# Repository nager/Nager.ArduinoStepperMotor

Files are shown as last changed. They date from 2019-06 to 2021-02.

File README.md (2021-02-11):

# Nager.ArduinoStepperMotor

This project was developed to control a stepper motor smoothly and to adjust the speed during operation. Most of the libaries I tested at that time had an acceleration curve but always stopped when changing to another speed and then started again. There are two ways to communicate with the Arduino, one is via serial communication or by using a network module. If you have difficulties and the motor only whistles you should adjust the acceleration curve in the Arduino file.

## Project Skier Simulator

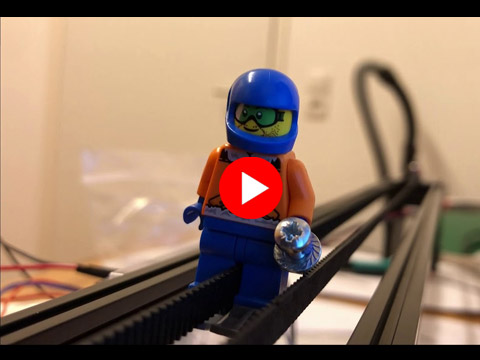
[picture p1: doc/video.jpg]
Youtube Video (https://www.youtube.com/watch?v=VNwVPjmE1V4)
<br>
Watch the video on Youtube

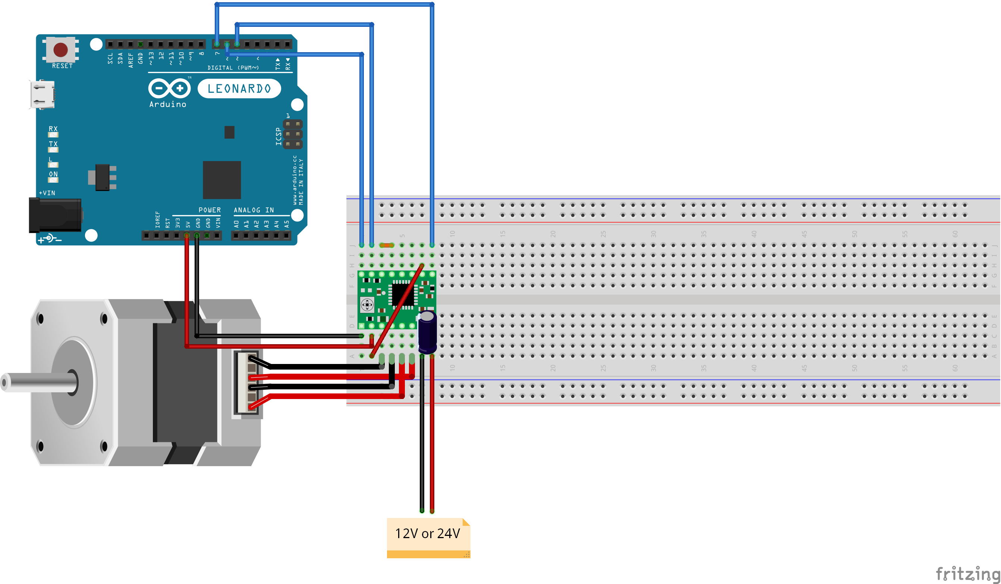
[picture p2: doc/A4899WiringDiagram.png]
A4899WiringDiagram

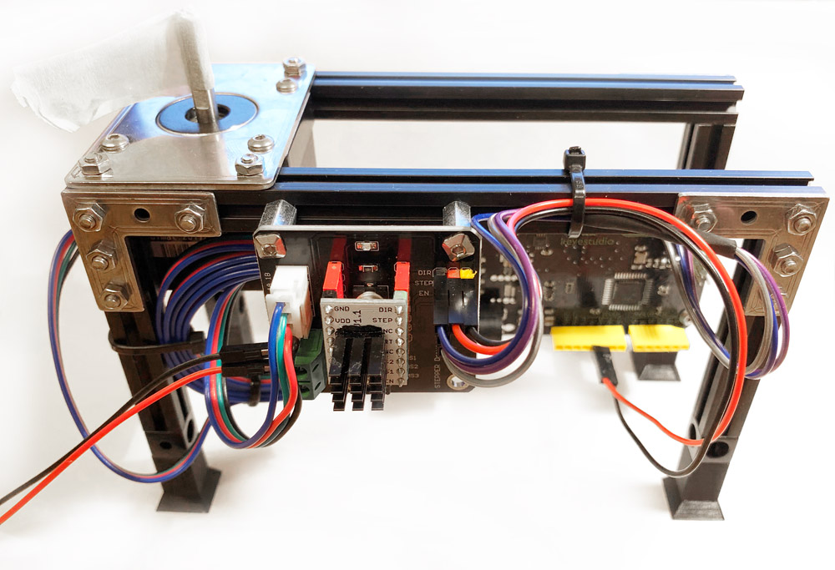
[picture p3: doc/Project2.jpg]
Project2


### Serial Commands (Baudrate 115200)

Command | Description | 
--- | --- | 
`enablemotordriver` | Enable the motor driver, the motor has voltage
`disablemotordriver` | Disable the motor driver, the motor has no voltage
`speed` | Values between -255 and 255
`limitenable` | The motor can only move between the limits
`limitdisable` | No limits active
`setlimitleft` | Set the current position as left limit
`setlimitright` | Set the current position as right limit
`step` | Motor move one step
`ramp` | Returns the current ramp
`setramp` | Set a new ramp (setramp=0008000) rampIndex 0 -> 8000

### Required Hardware

Quantity | Product | 
--- | --- | 
1x | [A4988 Stepper Driver Control Expansion Board](https://amzn.to/2X9j6cO) |
1x | [UEETEK 4 Stück 1M Stepper Motor Cable HX2.54 4-pin to 6-pin](https://amzn.to/31w3uz7) |
1x | [Usongshine Stepper Motor Nema 17 1.5A 17HS4401S](https://amzn.to/2KO4jO8) |
1x | [PChero Mechanic Endstop with LED Indicator](https://amzn.to/2UIAZh4) |

## Test Software

For control via serial communication I have developed a small test application.

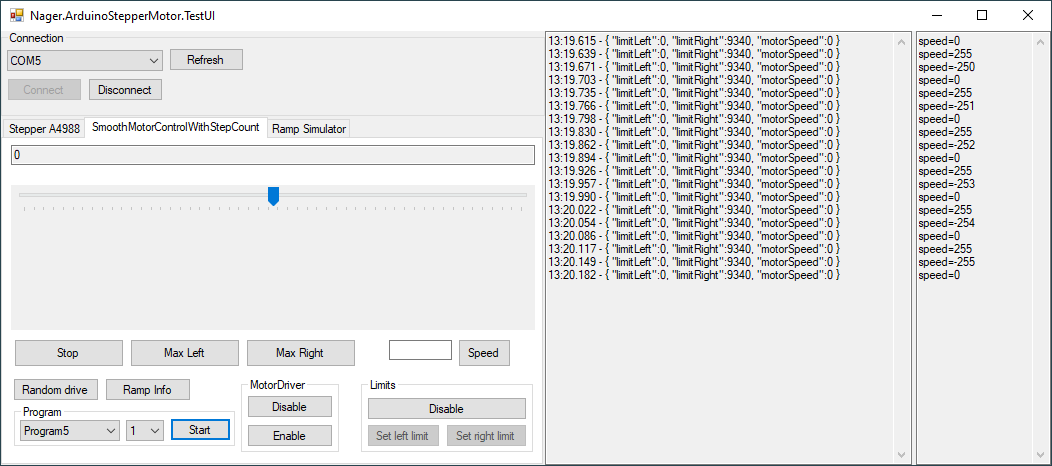
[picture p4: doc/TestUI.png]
TestUI


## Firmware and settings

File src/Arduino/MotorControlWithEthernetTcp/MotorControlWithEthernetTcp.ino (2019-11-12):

#include <SPI.h>
#include <Ethernet.h>

// Enter a MAC address and IP address for your controller below.
// The IP address will be dependent on your local network:
byte mac[] = { 0x06, 0x47, 0x3B, 0xA8, 0xF0, 0x9B };
IPAddress ip(192, 168 ,184, 65); //<<< ENTER YOUR IP ADDRESS HERE!!!

enum movementDirections {
  MOVEMENT_LEFT,
  MOVEMENT_RIGHT
};

int motorDriverActivePin = 7;
int stepPin = 5;
int directionPin = 6;

//Endstop configuration
bool endstopEnable = true;
int endstopRightPin = 2;
int endstopLeftPin = 3;

unsigned int counter = 0;
int onTime = 0;

String command = "";
bool limitActive = true;
unsigned long limitRight = 0;
unsigned long limitLeft = 0;
int motorDirection = 0; //0 or 1 rotates the motor direction

#define RAMP_STEPS 256
#define TIMERTICKS_PER_US 1

volatile unsigned int ramp[RAMP_STEPS];
volatile byte rampIndex = 0;
volatile int motorSpeed  = 0;
volatile unsigned long steps = 0;
volatile enum movementDirections movementDirection = MOVEMENT_RIGHT;
volatile enum movementDirections nextMovementDirection = MOVEMENT_RIGHT;

EthernetServer TcpServer = EthernetServer(23);
EthernetClient client;

void setup() {
  Serial.setTimeout(50);
  Serial.begin(115200);

  Ethernet.begin(mac, ip);
  TcpServer.begin();

  pinMode(motorDriverActivePin, OUTPUT); // Motor Driver Active
  pinMode(stepPin, OUTPUT); // Motor Step
  pinMode(directionPin, OUTPUT); // Motor Direction
  pinMode(endstopRightPin, INPUT); // Endstop

  digitalWrite(directionPin, motorDirection);
  digitalWrite(motorDriverActivePin, LOW);

  //https://www.heise.de/developer/artikel/Timer-Counter-und-Interrupts-3273309.html
  noInterrupts();           // disable all interrupts
  TCCR1A = 0;               // set entire TCCR1A register to 0
  TCCR1B = 0;               // set entire TCCR1B register to 0

  TCNT1 = 65534;

  //TCCR1B |= (1 << CS10);    // 4.1ms (No Prescale)
  TCCR1B |= (1 << CS11);    // 32.8ms (Prescale = 8)
  //TCCR1B |= (1 << CS12);    // 1049.6ms (Prescale = 256)
 
  TIMSK1 |= (1 << TOIE1);   // enable Timer1 overflow interrupt
  interrupts();             // enable all interrupts

  //caculateAccel(3000, 1, 0.6);
  //US-17HS4401S
  caculateAccel(1600, 1, 0.25);
  //caculateAccel(1500, 1, 0.6);
  //caculateAccel(300, 1, 0.2);

  //17HS13-0404S + A4988
  //caculateAccel(100, 200, 0.05);

  initialize();
  trinamicAutomaticTuning();
}

void caculateAccel(int startDelay, int angle, float acceleration) { 
  float c0 = startDelay * sqrt(2 * angle / acceleration) * 0.67703; // in us
  ramp[0] = c0 * TIMERTICKS_PER_US;
  float d = 0;
  float lastDelay = c0;

  for (int i = 1; i < RAMP_STEPS; i++) {
    d = lastDelay - (2 * lastDelay) / (4 * i + 1);
    ramp[i] = d * TIMERTICKS_PER_US;
    lastDelay = d;
  }
}

ISR(TIMER1_OVF_vect) {
  TCNT1 = 65536;

  if (rampIndex > 0) {
    onTime = ramp[rampIndex];
    TCNT1 = 65536 - onTime;

    checkLeftLimit();
    checkRightLimit();
    if (rampIndex == 0) {
      return;
    }

    //http://profhof.com/arduino-port-manipulation/
    //https://www.peterbeard.co/blog/post/why-is-arduino-digitalwrite-so-slow/
    digitalWrite(stepPin, HIGH);
    digitalWrite(stepPin, LOW);

    //stepPin = 5
    //PORTD |= B00001000;
    //PORTD &= B11110111;
    //PORTD = B00001000;
    //PORTD = B00000000;

    if (movementDirection == MOVEMENT_LEFT) {
      steps++;
    } else {
      steps--;
    }
  }

  if (movementDirection != nextMovementDirection) {
    //Slow down motor for direction switch
    if (rampIndex > 0) {
      rampIndex--;
    } else {
      switchDirection();
    }
  } else {
    //Change motor motorSpeed to a new ramp position
    if (motorSpeed > rampIndex) {
      rampIndex++;
    } else if (motorSpeed < rampIndex) {
      rampIndex--;
    }
  }
}

void loop() {

  int limitLeft = checkLeftLimit();
  int limitRight = checkRightLimit();

  if (!client) {
    client = TcpServer.available();
  }

  if (client) {
    if (client.connected()) {
      
      if (client.available()) {
        char dst[4];
        dst[0] = client.read();
        dst[1] = client.read();
        dst[2] = client.read();
        dst[3] = client.read();
        int nextSpeed = String(dst).toInt();
        if (nextSpeed > 0) {
          Serial.println("MOVEMENT_RIGHT");
          Serial.println(nextSpeed);
          nextMovementDirection = MOVEMENT_RIGHT;
          motorSpeed = abs(nextSpeed);
        } else {
          Serial.println("MOVEMENT_LEFT");
          Serial.println(nextSpeed);
          nextMovementDirection = MOVEMENT_LEFT;
          motorSpeed = abs(nextSpeed);
        }
      }
    } else {
      client.stop();
    }
  }
  
  commandProcessing();
  checkEndstops();

  //if (counter == 20000) {
  if (counter == 250) {
    Serial.println((String)"{ \"limitLeft\":" + limitLeft +  ", \"limitRight\":" + limitRight + ", \"motorSpeed\":" + motorSpeed + " }");
    counter = 0;
  }

  if (counter == 100) {
    if (client) {
      client.println((String) limitLeft +  ";" + limitRight + ";" + motorSpeed);
    }
  }

  delayMicroseconds(50);
  counter++;
}

void initialize() {
  steps = 2147483647;

  if (endstopEnable) {
    
    //Disable Limits
    limitActive = false;
  
    //Drive to right end position 
    for (int i = 1; i < 2000; i++) {
      motorSpeed = 1;
      if (digitalRead(endstopRightPin) == 0) {
        motorSpeed = 0;
        delay(1000);
        break;
      }
      delay(20);
    }
    motorSpeed = 0;
    limitRight = steps + 200;
  
    nextMovementDirection = MOVEMENT_LEFT;
  
    //Drive to left end position 
    for (int i = 1; i < 2000; i++) {
      motorSpeed = 1;
      if (digitalRead(endstopLeftPin) == 0) {
        motorSpeed = 0;
        delay(1000);
        break;
      }
      delay(20);
    }
    motorSpeed = 0;
    limitLeft = steps - 200;
  
    //Activate limits
    limitActive = true;
  }

    //Move away from limit
  nextMovementDirection = MOVEMENT_RIGHT;
  motorSpeed = 1;
  delay(500);
  motorSpeed = 0;
}

void trinamicAutomaticTuning() {
  //Trinamic Automatic Tuning TMC2208
  for (int i = 1; i <= 2; i++) {
    nextMovementDirection = MOVEMENT_LEFT;
    motorSpeed = RAMP_STEPS - 1;
    delay(1000);
    motorSpeed = 0;
    delay(300); //standstill more than 130ms
    nextMovementDirection = MOVEMENT_RIGHT;
    motorSpeed = RAMP_STEPS - 1;
    delay(1000);
    motorSpeed = 0;
    delay(300); //standstill more than 130ms
  }
}

void checkEndstops() {
  if (endstopEnable) {
    if (digitalRead(endstopRightPin) == 0) {
      digitalWrite(motorDriverActivePin, HIGH);
    }
  
    if (digitalRead(endstopLeftPin) == 0) {
      digitalWrite(motorDriverActivePin, HIGH);
    }
  }
}

void commandProcessing() {
  if (Serial.available() > 0) {
    command = Serial.readStringUntil('\n');

    if (command.startsWith("speed")) {
      int nextSpeed = command.substring(6).toInt();

      //Check speed is higher as max
      if (abs(nextSpeed) > RAMP_STEPS) {
        motorSpeed = 0;
        return;
      }

      if (nextSpeed > 0) {
        nextMovementDirection = MOVEMENT_RIGHT;
      } else if (nextSpeed < 0) {
        nextMovementDirection = MOVEMENT_LEFT;
      }

      motorSpeed = abs(nextSpeed);
    }

    if (command.equals("enablemotordriver")) {
      digitalWrite(motorDriverActivePin, LOW);
      return;
    }

    if (command.equals("disablemotordriver")) {
      digitalWrite(motorDriverActivePin, HIGH);
      return;
    }

    if (command.equals("limitenable")) {
      limitActive = true;
      return;
    }

    if (command.equals("limitdisable")) {
      limitActive = false;
      return;
    }

    if (command.equals("setlimitleft")) {
      limitLeft = steps;
      return;
    }

    if (command.equals("setlimitright")) {
      limitRight = steps;
      return;
    }

    if (command.equals("step")) {
      digitalWrite(stepPin, HIGH);
      digitalWrite(stepPin, LOW);
      return;
    }

    if (command.equals("ramp")) {
      Serial.print((String)"{ ramp:[");
      for (int i = 0; i < RAMP_STEPS; i++)
      {
        Serial.print((String)"" + ramp[i] + ",");
      }
      Serial.println((String)"] }");
    }

    if (command.startsWith("setramp=")) {
      //setramp=0008000 -> rampIndex 0 -> 8000
      //setramp=0017000 -> rampIndex 1 -> 7000
      //setramp=0026000 -> rampIndex 2 -> 6000
      int index = command.substring(8,11).toInt();
      int value = command.substring(11,16).toInt();
      ramp[index] = value;
    }
  }
}

int checkLeftLimit() {
  if (!limitActive) {
    return -1;
  }

  long distance = limitLeft - steps;

  if (nextMovementDirection == MOVEMENT_LEFT && distance < 400 && motorSpeed > 2) {
    int reduceSpeed = ceil(motorSpeed / 10.0);
    motorSpeed = motorSpeed - reduceSpeed;
  }

  if (movementDirection == MOVEMENT_LEFT && distance <= 0 && rampIndex != 0) {
    rampIndex = 0;
    motorSpeed = 0;
  }

  return distance;
}

int checkRightLimit() {
  if (!limitActive) {
    return -1;
  }

  long distance = steps - limitRight;

  if (nextMovementDirection == MOVEMENT_RIGHT && distance < 400 && motorSpeed > 2) {
    int reduceSpeed = ceil(motorSpeed / 10.0);
    motorSpeed = motorSpeed - reduceSpeed;
  }

  if (movementDirection == MOVEMENT_RIGHT && distance <= 0 && rampIndex != 0) {
    rampIndex = 0;
    motorSpeed = 0;
  }

  return distance;
}

void switchDirection() {
  if (movementDirection == nextMovementDirection){
    return;
  }
  
  if (nextMovementDirection == MOVEMENT_LEFT) {
    movementDirection = MOVEMENT_LEFT;
    digitalWrite(directionPin, !motorDirection);
    return;
  }
  
  movementDirection = MOVEMENT_RIGHT;
  digitalWrite(directionPin, motorDirection);
}

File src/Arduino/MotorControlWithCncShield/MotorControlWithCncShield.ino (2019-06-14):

#include <Arduino.h>
#include "A4988.h"

#define MOTOR_STEPS 200
// Microstepping mode. If you hardwired it to save pins, set to the same value here.
#define MICROSTEPS 4
//#define MICROSTEPS 1
// Target RPM for cruise speed
#define RPM 100

#define DIR 5
#define STEP 2
#define MS1 8

//https://github.com/laurb9/StepperDriver/blob/master/src/BasicStepperDriver.h
//https://blog.protoneer.co.nz/arduino-cnc-shield-v3-00-assembly-guide/

A4988 stepper(MOTOR_STEPS, DIR, STEP, MS1);

String command = "";
int speed = 0;
int rotate = 0;
unsigned wait_time_micros = 0;
int Led = 13 ;// define LED Interface

int pin9 = 0; //Endstop
int pin10 = 0; //Manual move
int pin11 = 0; //Manual move
bool autoMode = false;

void setup() {
  Serial.setTimeout(50);
  Serial.begin(115200);
  Serial.println("Starting");

  pinMode (Led, OUTPUT) ;// define LED as output interface
  
  //stepper.begin(RPM, MICROSTEPS);
  //stepper.begin(200, MICROSTEPS);
  stepper.begin(RPM, MICROSTEPS);
  stepper.setEnableActiveState(LOW); //important if stepper.disable not work
  stepper.enable();
  stepper.rotate(100);
  delay(100);
  stepper.rotate(-100);

  //stepper.setSpeedProfile(stepper.CONSTANT_SPEED, 300, 300);
  //stepper.setSpeedProfile(stepper.LINEAR_SPEED, 300, 300);

  stepper.disable();

  Serial.println("Ready");
  
  //pinMode(2, OUTPUT); //Movement, Steps
  //pinMode(5, OUTPUT); //Direction
  //pinMode(8, OUTPUT); //Motor

  pinMode(11, INPUT_PULLUP); //
  pinMode(10, INPUT_PULLUP); //
  pinMode(9, INPUT_PULLUP); //
}

void loop() {

  pin9 = digitalRead(9);
  pin10 = digitalRead(10);
  pin11 = digitalRead(11);

  if (pin9 == 0) {
    stepper.stop();
    autoMode = false;
    return;
  }

  if (pin10 == 0 && pin11 == 0) {
    autoMode = true;
  }

  if (autoMode) {
    stepper.enable();
    stepper.move(10000);
    delay(1000);
    stepper.move(-10000);
    stepper.disable();
    delay(1000);
  }

/*
  Serial.print(pin9,HEX);
  Serial.print(pin10,HEX);
  Serial.print(pin11,HEX);
  Serial.println();
*/

  if (pin10 == 0) {
    stepper.enable();
    stepper.startMove(10000);
  }

  if (pin11 == 0) {
    stepper.enable();
    stepper.startMove(-10000);
  }
  
  wait_time_micros = stepper.nextAction();
  if (wait_time_micros > 0) {
    //Serial.println(wait_time_micros);
    //Serial.println(stepper.getSteps());
  }
  if (wait_time_micros == 0) {
    stepper.disable();
  }

  if (Serial.available() > 0) {
    command = Serial.readString();
    if (command == "start") {
      Serial.println("enable stepper");
      stepper.enable();
      digitalWrite(Led, HIGH);
    }
    if (command == "stop") {
      Serial.println("disable stepper");
      stepper.stop();
      stepper.disable();
      digitalWrite(Led, LOW);
    }
    if (command.startsWith("move")) {
         
      rotate = command.substring(5).toInt();

      //stepper.startMove(rotate * 15 * 200);
      stepper.startMove(rotate);
      Serial.println(rotate);
    }
    if (command.startsWith("speed")) {
      speed = command.substring(6).toInt();
      stepper.begin(speed, MICROSTEPS);
      Serial.println(speed);
    }
  }
}

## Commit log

2019-03-27 add fritzing file
    [ConnectionDiagram.fzz]
2019-04-02 update image
    [ConnectionDiagram.fzz]
2019-06-05 Add new arduino motor logic
2019-06-28 Optimize motor slow down before limits
2019-07-09 Add a second endStop, add testui image
2019-07-16 Add logic to disable endstops
2019-07-31 some small fixes for ramp
    [SmoothMotorControlWithStepCount.ino]
2019-08-04 Update documentation
    [A4899WiringDiagram.fzz, CncShieldWiringDiagram.fzz]
2021-01-29 Bump log4net in /src/Nager.ArduinoStepperMotor.TestUI
    Bumps [log4net](https://github.com/apache/logging-log4net) from 2.0.8 to 2.0.10.
    - [Release notes](https://github.com/apache/logging-log4net/releases)
    - [Changelog](https://github.com/apache/logging-log4net/blob/master/ReleaseInstructions.txt)
    - [Commits](https://github.com/apache/logging-log4net/compare/rel/2.0.8...rel/2.0.10)
2021-03-20 Optimize Arduino Motor logic
    cleanup, optimize structure, fix endstop bug
    [SmoothMotorControlWithStepCount.ino]
2022-06-22 Bump Newtonsoft.Json in /src/Nager.ArduinoStepperMotor.TestUI
    Bumps [Newtonsoft.Json](https://github.com/JamesNK/Newtonsoft.Json) from 12.0.2 to 13.0.1.
    - [Release notes](https://github.com/JamesNK/Newtonsoft.Json/releases)
    - [Commits](https://github.com/JamesNK/Newtonsoft.Json/compare/12.0.2...13.0.1)
    ---
    updated-dependencies:
    - dependency-name: Newtonsoft.Json
    dependency-type: direct:production
    ...
